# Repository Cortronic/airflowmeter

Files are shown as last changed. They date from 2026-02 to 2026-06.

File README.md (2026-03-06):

# Zero-Pressure Compensated Airflow Meter

<p align="left">
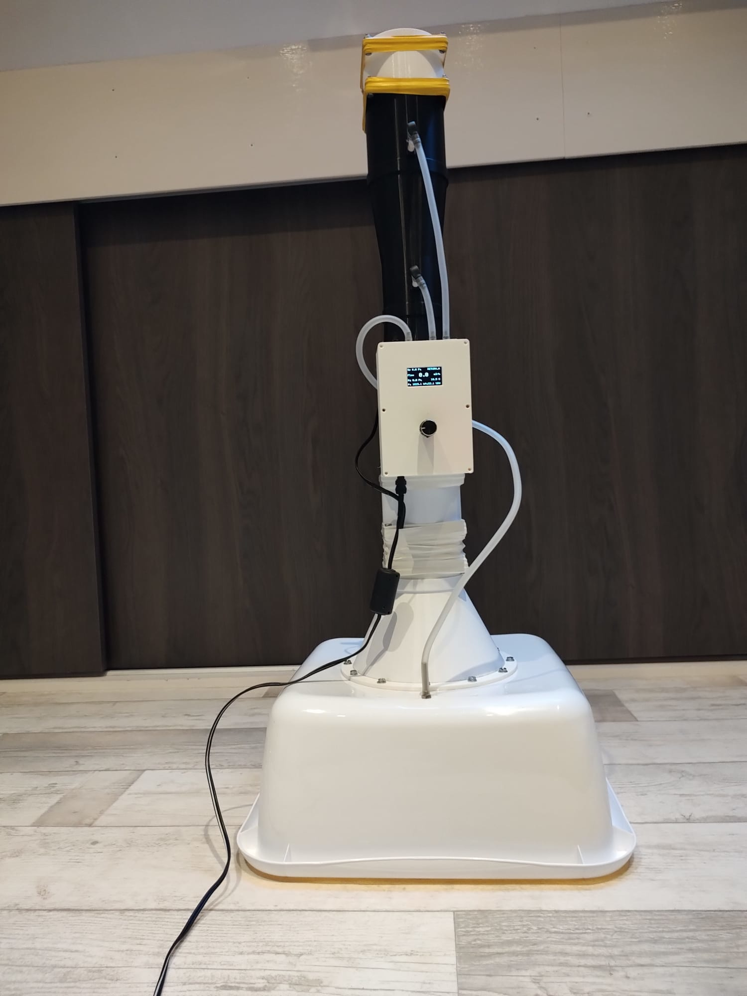
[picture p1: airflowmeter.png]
  
</p>

An open-source, high-precision instrument designed for measuring air flow in residential ventilation systems (HRV/MVHR). By using active zero-pressure compensation, this device eliminates its own pneumatic resistance, providing "invisible" measurements that do not disturb the ventilation system's balance.

## 1. Core Principle

Traditional flow hoods create backpressure, leading to underestimated flow readings. This device uses a secondary **SDP800-500PA** differential pressure sensor to monitor the pressure inside the hood. An integrated **Arctic S8038-10K fan** is controlled via a PID loop to maintain exactly $0.0\text{ Pa}$ relative to the room.

---

## 2. Hardware Architecture

The **ESP32-WROOM** utilizes two independent I2C buses to ensure high-speed data acquisition without bus collisions between identical sensors.

### Pinout Configuration

| Component | Function | ESP32 GPIO | Notes |
| --- | --- | --- | --- |
| **I2C Bus 0** | Data / Clock | **21 / 22** | BME280, OLED, SDP800 (Venturi) |
| **I2C Bus 1** | Data / Clock | **25 / 26** | SDP800 (Zero-Pressure Sensor) |
| **Encoder** | CLK / DT / SW | **2, 4, 15** | Menu & Calibration |
| **PWM Fan** | Speed Control | **27** | 25kHz PWM signal |

---

## 3. User Interface & Menu Structure

The 1.3" OLED (SH1106) provides a high-density data overview using a context-aware interface.

### Navigation Logic

* **Short Press:** Opens the **Quick-Profile Menu** to switch between calibrated profiles (Axial/Radial - Supply/Extract).
* **Long Press (>2s):** Enters the **System Menu** (Back, Tune Zero-Comp, Tune Flow, Tune PID).

### Display Layout (Measurement Mode)

The screen is optimized for the SH110X library using `textsize 1` and `textsize 2`.

| Position | Content | Example |
| --- | --- | --- |
| **Top Left** | Active Setpoint | `Set: 1.25 Pa` |
| **Top Right** | Profile Name | `RAD-SUPPLY` |
| **Center** | **Flow Rate** | **125.4 m3/h** |
| **Row 3** | Hood P / Temp | `P: 0.1 Pa` / `21.2 C` |
| **Bottom** | Baro / Hum | `1014 hPa` / `42 %` |

---

## 4. Interactive Calibration (Live-Trim)

The device uses a "Live-Trim" methodology. Settings are automatically saved to the active profile in the **NVS Flash** memory (`Preferences.h`).

* **Tune Zero-Comp:** Adjust the setpoint (range -25 to +25 Pa) while connected to the [test bench](https://github.com/Cortronic/testbench_airflowmeter) to compensate for air impingement (common in radial valves).
* **Tune Flow:** Rotate the encoder to align the meter's flow reading with the [reference Test Bench](https://github.com/Cortronic/testbench_airflowmeter).
* **Tune PID:** Select P, I, or D using **inverse video highlighting**. Adjust parameters in real-time and observe fan stability immediately.

---

## 5. Scientific Calculations

### Air Density ($\rho$)

Precision is maintained by calculating the density of moist air using the **Magnus-Tetens** approximation:

$$\rho = \frac{p_{dry}}{R_d \cdot T} + \frac{p_{vapor}}{R_v \cdot T}$$

### Volumetric Flow ($Q$)

Calculated based on the pressure differential across the Venturi throat:

$$Q = 3600 \cdot C_d \cdot A_{throat} \cdot \sqrt{\frac{2 \cdot \Delta P}{\rho \cdot (1 - \beta^4)}}$$

Where Beta ($$\beta$$) equals to:

$$\beta = \frac{D_{throat}}{D_{inlet}}$$

---

## 6. Manufacturing & Assembly

### 3D Printing

* **Material:** **PETG** (0.2mm layer height) for structural integrity and heat resistance.
* **Venturi Tube:** Printed in three sections (Inlet, Throat, Outlet) and bonded with **epoxy resin**.
* **Direct Drive:** Highly recommended to minimize stringing in PETG parts.

### Aerodynamics & Pressure Sensing

* **Dual Piezometric Rings:** The final Venturi design features integrated pressure rings at both the inlet and the throat. Each ring averages the static pressure from multiple points to ensure high accuracy.
* **Flow Hood Sensing:** The flow hood utilizes a 12-port averaging ring (2.5mm ports) to provide a stable signal for the zero-pressure logic.
* **Reversible Adapters:** Custom adapters allow the flow hood to be mounted on either side of the core assembly. This allows switching between supply and extract measurements while maintaining optimal aerodynamic orientation for the fan and Venturi.

---

## 7. License

This project is licensed under the **MIT License**.

---

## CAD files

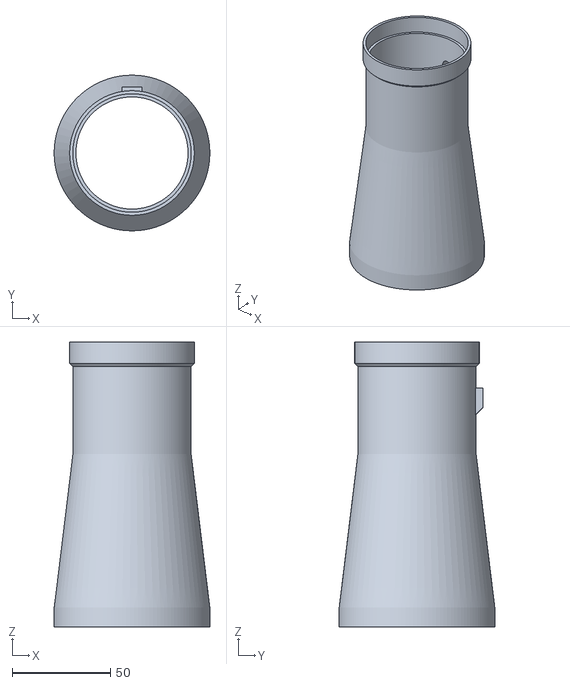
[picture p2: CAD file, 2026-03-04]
stl/venturi.stl
79.2 x 79.2 x 145.0

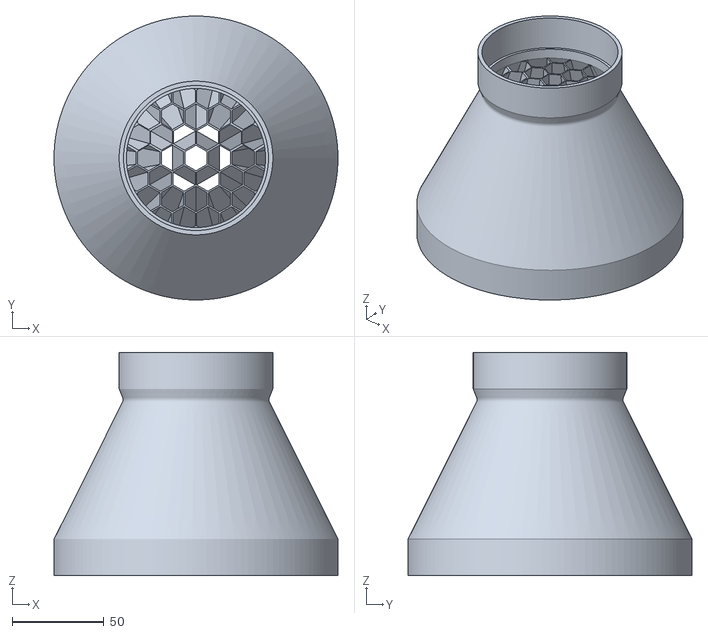
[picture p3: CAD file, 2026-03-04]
stl/adapter_v1.0.stl
155.2 x 155.2 x 122.0

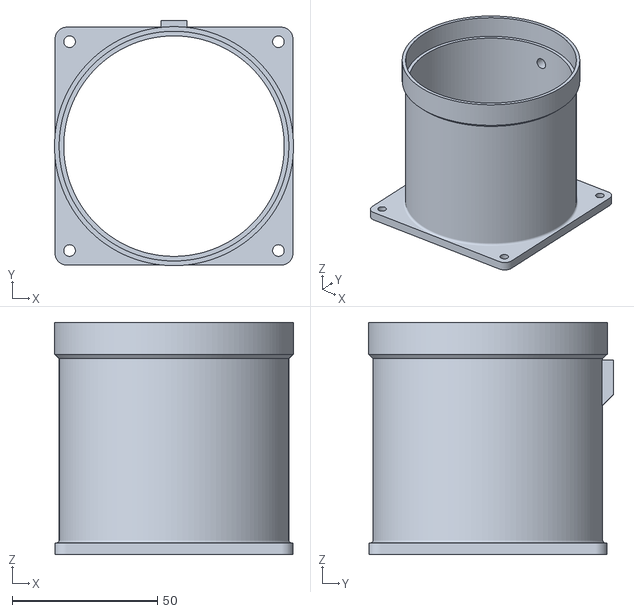
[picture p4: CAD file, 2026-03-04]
stl/Inlet.stl
82.4 x 84.5 x 80.0

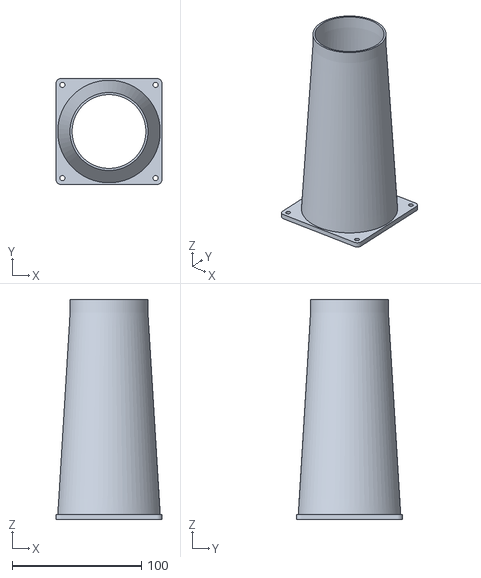
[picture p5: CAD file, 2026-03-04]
stl/outlet.stl
82.0 x 82.0 x 170.0

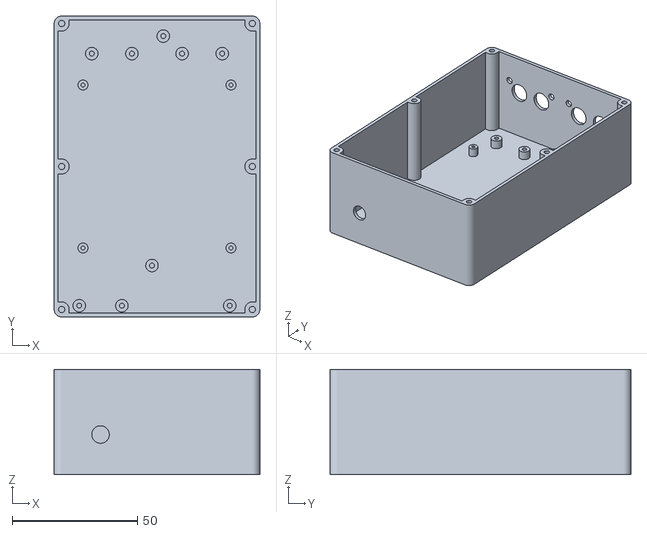
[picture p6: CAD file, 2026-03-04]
stl/bodycase.stl
82.0 x 120.0 x 42.0

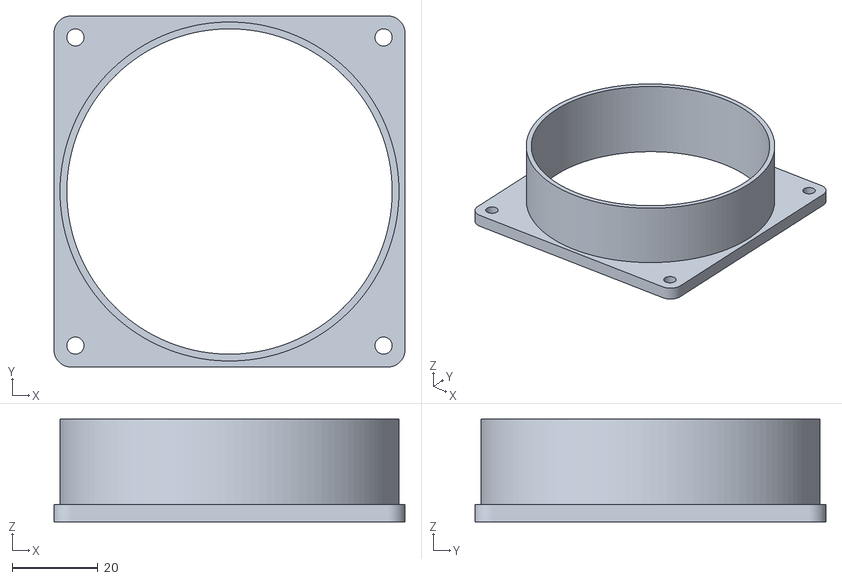
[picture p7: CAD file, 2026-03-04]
stl/adapterflange.stl
82.0 x 82.0 x 24.0

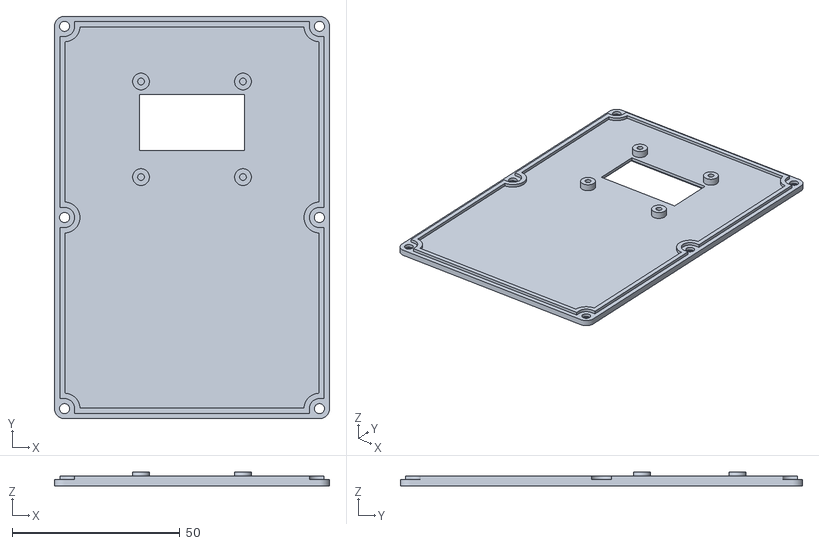
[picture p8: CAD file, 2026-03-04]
stl/bodylid.stl
82.0 x 120.0 x 4.30

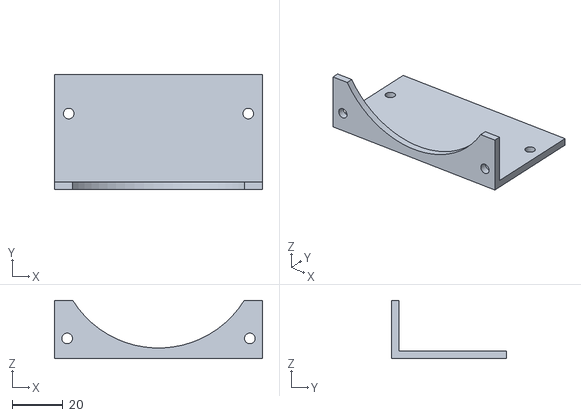
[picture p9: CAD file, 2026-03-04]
stl/steun-behuizing.stl
82.0 x 45.5 x 23.0

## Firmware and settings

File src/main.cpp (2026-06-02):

#include <Arduino.h>

#include <Preferences.h>
#include <Wire.h>
#include <AiEsp32RotaryEncoder.h>
#include <AiEsp32RotaryEncoderNumberSelector.h>
#include <SensirionCore.h>
#include <SensirionI2CSdp.h>
#include <Adafruit_SH110X.h>
#include <Adafruit_Sensor.h>
#include <Adafruit_BME280.h>
#include <PID_v1.h>
#include <Smoothed.h>
#include "fan.h"
#include "venturi.h"
#include "main.h"

// Pin definitions
// 12C pins
const int I2C_SDA0_PIN = 21;
const int I2C_SCL0_PIN = 22;
const int I2C_SDA1_PIN = 25;
const int I2C_SCL1_PIN = 26;

// Rotary encoder
const int ROTARY_ENCODER_A_PIN = 2; // 18;
const int ROTARY_ENCODER_B_PIN = 4; //19;
const int ROTARY_ENCODER_BUTTON_PIN = 15; //5;
const int ROTARY_ENCODER_STEPS = 4;

// Display
const int I2C_ADDRESS_DISPLAY = 0x3C;
const int I2C_ADDRESS_BME280  = 0x76;
const int I2C_ADDRESS_SDP810  = 0x25;

// PWM settings
const int PWM_FAN_PIN = 27;
const int PWM_FAN_CHAN = 0;
const int PWM_FREQ = 25000;    // 25 kHz frequency for computer fans
const int PWM_RESOLUTION = 10; // 10-bit resolution (0-1023)
const int PWM_DITHER_RESOLUTION = 2; // 2 bits of dithering for finer control

// paramaters for button press detection
const unsigned long shortPressAfterMiliseconds = 50;   // how long short press shoud be.
                                                       // Do not set too low to avoid bouncing (false press events).
const unsigned long longPressAfterMiliseconds = 1000;  // how long long press shoud be.

AiEsp32RotaryEncoder *rotaryEncoder = new AiEsp32RotaryEncoder(ROTARY_ENCODER_A_PIN, ROTARY_ENCODER_B_PIN,
  ROTARY_ENCODER_BUTTON_PIN, -1, ROTARY_ENCODER_STEPS, false);
AiEsp32RotaryEncoderNumberSelector numberSelector = AiEsp32RotaryEncoderNumberSelector();

Fan fan(PWM_FAN_PIN, PWM_FAN_CHAN, PWM_FREQ, PWM_RESOLUTION, PWM_DITHER_RESOLUTION);
// Venturi
Venturi venturi;

Preferences preferences;

Smoothed<float> zeroPressure;
Smoothed<float> flowPressure;
Smoothed<float> pressureAmbient;
Smoothed<float> temperatureAmbient;
Smoothed<float> humidityAmbient;
Smoothed<float> calibration;

/**
 * Two hardware I2C busses, one for the display, the BME280 and one SPD810 sensor.
 * The other for the second SDP810 sensor, to avoid address conflict between the two sensors.
 * The display and BME280 are on the same bus as they are not time critical and can handle the occasional delay 
 * and do not interfere with the timing of the SDP810 sensors.
 */
TwoWire I2C_A = TwoWire(0);
TwoWire I2C_B = TwoWire(1);

SensirionI2CSdp sdpFlow;
SensirionI2CSdp sdpZero;

// Initialize the OLED display using Wire library
Adafruit_SH1106G display(128, 64, &I2C_A);
Adafruit_BME280  bme280;     
hw_timer_t *timer0 = nullptr;
volatile bool ms10_passed = false;

ModeType modeType = MT_MEASURE;
ValveType valveType = VT_EXTRACT_RADIAL;
PidTuneType pidTuneType = PID_TUNE_NONE;

bool direction = false; // false for air extraction, true for air supply

// Define PID Variables
double pidSetpoint, pidInput, pidOutput;

// Specify the links and initial tuning parameters
double Kp = 6, Ki = 3, Kd = 0;
PID pid(&pidInput, &pidOutput, &pidSetpoint, Kp, Ki, Kd, REVERSE);

float offsetZeroPressure;
float offsetFlowPressure;

float compensationFactorEA = 0.0;
float compensationFactorER = 0.0;
float compensationFactorSA = 0.0;
float compensationFactorSR = 0.0;

float flowFactorExtractAxial = 0.985;
float flowFactorExtractRadial = 0.985;
float flowFactorSupplyAxial = 0.985;
float flowFactorSupplyRadial = 0.985;

static void  loadPreferences();
static void  setupRotaryEncoder();
static void  loopRotaryEncoder();
static void  readPressureSensors();
static float calculateZeroCompensationPressure();
static void  setupTimer0();
static void  initDisplay(void);
static void  displayAdjustSensorOffsetsProgress(int16_t progress);
static void  displayAdjustSensorOffsets(const char *sensor);
static void  displayTextNumber(const char *txt, float);
static void  displayMeasurements();
static void  displaySelectMode(ModeType type);
static void  displaySelectTunePID(PidTuneType type);
static void  displaySelectValveMode(ValveType type);
static void  displayCoefficientFlow(float coef);
static void  displayCoefficientZeroCompensation();
static void  initBME280();
static void  initSDP(SensirionI2CSdp&, TwoWire&);
static void  drawString(int16_t x, int16_t y, const String &text);
static float getDischargeCoefficient();
static void saveDischargeCoefficient(float coef);
//////////////////////////////////////////////////////////////////////////

// Interrupt Service Routine (ISR)
// IRAM_ATTR places the function in RAM for faster execution
void IRAM_ATTR Timer0_ISR() {
  ms10_passed = true;
  fan.handleDither(); // Handle fan dithering if enabled
}
//////////////////////////////////////////////////////////////////////////

void IRAM_ATTR readEncoder_ISR() {
    rotaryEncoder->readEncoder_ISR();
}
//////////////////////////////////////////////////////////////////////////

void IRAM_ATTR readButton_ISR() {
    rotaryEncoder->readButton_ISR();
}
//////////////////////////////////////////////////////////////////////////

void setup() {
  Serial.begin(115200);

  Serial.println("\nAirflowmeter is starting up...");

  loadPreferences();

  // setup RotaryEncoder
  setupRotaryEncoder();

  // Configure PWM
  Serial.println("Setup PWM for fan control");
  fan.begin();
  delay(500);

  // Start both busses
  I2C_A.begin(I2C_SDA0_PIN, I2C_SCL0_PIN, 700000);   // SDA, SCL
  I2C_B.begin(I2C_SDA1_PIN, I2C_SCL1_PIN, 100000);

  Serial.println("Setup Display");
  initDisplay();
  delay(500);
  Serial.println("Setup BME280");
  initBME280();
  delay(500);
  Serial.println("Setup SDP810 Flow");
  initSDP(sdpFlow, I2C_A);
  delay(500);
  Serial.println("Setup SDP810 Zero");
  initSDP(sdpZero, I2C_B);
  delay(500);

  Serial.println("setup smoothed average.");
  zeroPressure.begin(SMOOTHED_EXPONENTIAL, 2);
  flowPressure.begin(SMOOTHED_AVERAGE, 100);
  pressureAmbient.begin(SMOOTHED_AVERAGE, 40);
  humidityAmbient.begin(SMOOTHED_AVERAGE, 40);
  temperatureAmbient.begin(SMOOTHED_AVERAGE, 40);
  calibration.begin(SMOOTHED_AVERAGE, 200);

  bme280.takeForcedMeasurement();
  pressureAmbient.add(bme280.readPressure());
  temperatureAmbient.add(bme280.readTemperature());
  humidityAmbient.add(bme280.readHumidity());
  delay(500);

  pidSetpoint = 0.0;
  pidInput = 0.0;

  // turn the PID on
  Serial.println("turn the PID on.");
  pid.SetTunings(Kp, Ki, Kd);
  pid.SetMode(AUTOMATIC);
  // set output limits according to PWM resolution and dithering
  pid.SetOutputLimits(0, (((1 << PWM_RESOLUTION) - 1) << PWM_DITHER_RESOLUTION)); 
  pid.SetControllerDirection(direction ? REVERSE : DIRECT);
  
  delay(500);
  
  Serial.print("Setup timer interrupt\n");
  setupTimer0();
  delay(500);

  Serial.print("\n Setup done...\n\n");
  delay(500);
}
//////////////////////////////////////////////////////////////////////////

void loop() {
  static uint32_t loopcnt = 0;
  static uint32_t loopCount = 0;
  static uint32_t last_millis = 0;
  uint32_t ms = millis();
  
  ++loopCount;
  
  readPressureSensors();

  loopRotaryEncoder();

  // every 100ms
  if (ms >= last_millis + 100) {
    last_millis = ms;

    pidSetpoint = calculateZeroCompensationPressure(); 
    pidInput = zeroPressure.get();
    
    pid.Compute();
    // Apply PWM to fan
    fan.setSpeed(pidOutput);

    readPressureSensors();
    
    // every second
    if (loopcnt % 10 == 0) {

      // Only needed in forced mode! In normal mode, you can remove the next line.
      bme280.takeForcedMeasurement(); // has no effect in normal mode
      readPressureSensors();

      // get the measurements from the BME280
      pressureAmbient.add(bme280.readPressure()); // Pressure in Pa
      readPressureSensors();
      temperatureAmbient.add(bme280.readTemperature()); // Temperature in °C
      readPressureSensors();
      humidityAmbient.add(bme280.readHumidity()); // Humidity in %
      readPressureSensors();

      Serial.printf("delay: %u\n", millis() - ms);
      Serial.printf("Loop count: %u\n", loopCount); // 168 loops/second
      Serial.printf("Flow pressure: %.1f Pa\n", flowPressure.get());
      Serial.printf("Zero presssure: %.1f Pa\n", zeroPressure.get());
      Serial.printf("PWM fan dutycycle: %.1f%%\n", pidOutput/(((1 << PWM_RESOLUTION)-1) << PWM_DITHER_RESOLUTION) * 100);
      loopCount = 0;
      // 13ms
      // Serial.printf("Loop duaration: %u\n", millis()- last_millis);
    }
    
    // every 2 seconds
    if (loopcnt++ % 20 == 0) {
      if (modeType == MT_MEASURE 
          || modeType == MT_TUNE_ZERO_COMPENSATION
          || modeType == MT_CALIBRATE_FLOW
          || pidTuneType == PID_TUNE_P
          || pidTuneType == PID_TUNE_I
          || pidTuneType == PID_TUNE_D
        ) {
        displayMeasurements(); // takes 42ms
      }
    }

     // every minute
    if (loopcnt % 600 == 0) {
       venturi.setRho(pressureAmbient.get(), temperatureAmbient.get(), humidityAmbient.get());
       readPressureSensors();
    }
  }
}
//////////////////////////////////////////////////////////////////////////

static void setupTimer0() {
  // 1. Initialize timer
  //timerBegin(timer_number, divider, countUp)
  // Prescaler 80: 80MHz / 80 = 1MHz (1 microsecond per tick)
  timer0 = timerBegin(0, 80, true);

  // 2. Attach the ISR function
  timerAttachInterrupt(timer0, &Timer0_ISR, true);

  // 3. Set alarm to fire every 10000 ticks (10000 us = 10ms)
  // timerAlarmWrite(timer, microseconds, autoreload)
  timerAlarmWrite(timer0, 10000, true);

  // 4. Enable the alarm
  timerAlarmEnable(timer0);
}
//////////////////////////////////////////////////////////////////////////

static void setupRotaryEncoder() {
  rotaryEncoder->begin();
  rotaryEncoder->setup(&readEncoder_ISR, &readButton_ISR);
  numberSelector.attachEncoder(rotaryEncoder);

  // numberSelector.setRange parameters:
  float minValue = -20.0;      // set minimum value for example -12.0
  float maxValue = 20.0;       // set maxinum value for example 12.0
  float step = 0.1;            // set step increment, default 1, can be smaller steps like 0.5 or 10
  bool cycleValues = false;    // set true only if you want going to miminum value after maximum 
  unsigned int decimals = 1;   // set precision - how many decimal places you want, default is 0
  numberSelector.setRange(minValue, maxValue,  step, cycleValues, decimals);
  numberSelector.setValue(0.0); // sets initial value
}
//////////////////////////////////////////////////////////////////////////

static void setValveType(ValveType type) {
  valveType = type;

  venturi.setDischargeCoefficient(getDischargeCoefficient());
  
  switch(type) {
    case VT_EXTRACT_AXIAL:
    case VT_EXTRACT_RADIAL:
      direction = false;
      break;
    
    case VT_SUPPLY_AXIAL:  
    case VT_SUPPLY_RADIAL:
      direction = true;
      break;
  }
  pid.SetControllerDirection(direction ? REVERSE : DIRECT);

}
//////////////////////////////////////////////////////////////////////////

static float getFloat(const char* key, float value = NAN) {
  float f;
  preferences.begin("airflow", false);
  f = preferences.getFloat(key, value);
  preferences.end();
  return f == NAN ? 0.0 : f;
}
//////////////////////////////////////////////////////////////////////////

static void saveFloat(const char* key, float value) {
  preferences.begin("airflow", false);
  preferences.putFloat(key, value);
  preferences.end();
}
//////////////////////////////////////////////////////////////////////////

static void loadPreferences() {
  preferences.begin("airflow", true);

  offsetZeroPressure = preferences.getFloat(OFFSET_ZERO_PRESSURE, 0.0);
  offsetFlowPressure = preferences.getFloat(OFFSET_FLOW_PRESSURE, 0.0);

  float temp = preferences.getFloat(FLOW_COEF_EXTRACT_AXIAL, 0.0);
  if (temp >= FLOW_COEF_MIN && temp <= FLOW_COEF_MAX) {
    flowFactorExtractAxial = temp;
  }
  temp = preferences.getFloat(FLOW_COEF_EXTRACT_RADIAL, 0.0);
  if (temp >= FLOW_COEF_MIN && temp <= FLOW_COEF_MAX) {
    flowFactorExtractRadial = temp;
  }
  temp = preferences.getFloat(FLOW_COEF_SUPPLY_AXIAL, 0.0);
  if (temp >= FLOW_COEF_MIN && temp <= FLOW_COEF_MAX) {
    flowFactorSupplyAxial = temp;
  }
  temp = preferences.getFloat(FLOW_COEF_SUPPLY_RADIAL, 0.0);
  if (temp >= FLOW_COEF_MIN && temp <= FLOW_COEF_MAX) {
    flowFactorSupplyRadial = temp;
  }

  float inletDiameter = preferences.getFloat(KEY_VENTURI_INLET_DIAMETER, 0.076);
  float throatDiameter = preferences.getFloat(KEY_VENTURI_THROAT_DIAMETER, 0.057);
  venturi.begin(inletDiameter, throatDiameter, getDischargeCoefficient());
  venturi.setSmoothedFlowFactor(preferences.getFloat(KEY_VENTURI_SMOOTHING_FACTOR, 0.02));

  compensationFactorEA = preferences.getFloat(ZERO_COMPENSATION_FACTOR_EA, 0.0);
  compensationFactorER = preferences.getFloat(ZERO_COMPENSATION_FACTOR_ER, 0.0);
  compensationFactorSA = preferences.getFloat(ZERO_COMPENSATION_FACTOR_SA, 0.0);
  compensationFactorSR = preferences.getFloat(ZERO_COMPENSATION_FACTOR_SR, 0.0);

  // initialize the PID variables
  Kp = preferences.getFloat(Kp_KEY, Kp);
  Ki = preferences.getFloat(Ki_KEY, Ki);
  Kd = preferences.getFloat(Kd_KEY, Kd);

  preferences.end();
}
//////////////////////////////////////////////////////////////////////////

static void adjustSensorOffsetFlowPressure() {
  Serial.println("Adjusting offset flowsensor."); 
  for (size_t i = 0; i < 200; i++) {
    float differentialPressure;
    float temperature;
    uint16_t error = sdpFlow.readMeasurement(differentialPressure, temperature);
    if (error) {
       Serial.print("Error trying to execute readMeasurement() from flowsensor");
       break;
    }
    calibration.add(differentialPressure);
    if (i % 12 == 0) {
      displayAdjustSensorOffsetsProgress(i * 120 / 200);
    }
    delay(15);
  }

  offsetFlowPressure = calibration.get();
  saveFloat(OFFSET_FLOW_PRESSURE, offsetFlowPressure);
  Serial.printf("offset flow %f\n", offsetFlowPressure);
  delay(500); 
}
//////////////////////////////////////////////////////////////////////////

static void adjustSensorOffsetZeroPressure() {
  Serial.println("Adjusting offset zeropressuresensor."); 
  for (size_t i = 0; i < 200; i++) {
    float differentialPressure;
    float temperature;
    uint16_t error = sdpZero.readMeasurement(differentialPressure, temperature);
    if (error) {
       Serial.print("Error trying to execute readMeasurement() from zeropressuresensor");
       break;
    }
    calibration.add(differentialPressure);
    if (i % 12 == 0) {
      displayAdjustSensorOffsetsProgress(i * 120 / 200);
    }
    delay(15);
  }
  
  offsetZeroPressure = calibration.get();
  saveFloat(OFFSET_ZERO_PRESSURE, offsetZeroPressure);
  Serial.printf("offset zero %f\n", offsetZeroPressure);
  delay(500); 
}
//////////////////////////////////////////////////////////////////////////

static void adjustSensorOffsets() {
  displayAdjustSensorOffsets("Zero");
  adjustSensorOffsetZeroPressure();
  displayAdjustSensorOffsets("Flow");
  adjustSensorOffsetFlowPressure();
}
//////////////////////////////////////////////////////////////////////////

static float getZeroCompensationFactor() {
  switch (valveType) {
    case VT_EXTRACT_AXIAL:
      return compensationFactorEA;
    case VT_EXTRACT_RADIAL:
      return compensationFactorER;
    case VT_SUPPLY_AXIAL:
      return compensationFactorSA;
    case VT_SUPPLY_RADIAL:
      return compensationFactorSR; 
  }
  return 0.0;
}
//////////////////////////////////////////////////////////////////////////

static void setZeroCompensationFactor(float factor) {
  switch (valveType) {
    case VT_EXTRACT_AXIAL:
      compensationFactorEA = factor;
      break;
    case VT_EXTRACT_RADIAL:
      compensationFactorER = factor;
      break;
    case VT_SUPPLY_AXIAL:
      compensationFactorSA = factor;
      break;
    case VT_SUPPLY_RADIAL:
      compensationFactorSR = factor; 
      break;
  }
}
//////////////////////////////////////////////////////////////////////////

static void saveZeroCompensationFactor(float factor) {
  
  switch (valveType) {
    case VT_EXTRACT_AXIAL:
      compensationFactorEA = factor;
      saveFloat(ZERO_COMPENSATION_FACTOR_EA, factor);
      break;
    case VT_EXTRACT_RADIAL:
      compensationFactorER = factor;
      saveFloat(ZERO_COMPENSATION_FACTOR_ER, factor);
      break;
    case VT_SUPPLY_AXIAL:
      compensationFactorSA = factor;
      saveFloat(ZERO_COMPENSATION_FACTOR_SA, factor);
      break;
    case VT_SUPPLY_RADIAL:
      compensationFactorSR = factor; 
      saveFloat(ZERO_COMPENSATION_FACTOR_SR, factor);
      break;
  }
}
//////////////////////////////////////////////////////////////////////////

static void restoreZeroCompensationFactors() {
  switch(valveType) {
    case VT_EXTRACT_AXIAL:
      compensationFactorEA = getFloat(ZERO_COMPENSATION_FACTOR_EA, 0.0);
      pidSetpoint = compensationFactorEA * flowPressure.get();
      break;
    case VT_EXTRACT_RADIAL:
      compensationFactorER = getFloat(ZERO_COMPENSATION_FACTOR_ER, 0.0);
      pidSetpoint = compensationFactorER * flowPressure.get();
      break;
    case VT_SUPPLY_AXIAL:
      compensationFactorSA = getFloat(ZERO_COMPENSATION_FACTOR_SA, 0.0);
      pidSetpoint = compensationFactorSA * flowPressure.get();
      break;
    case VT_SUPPLY_RADIAL:
      compensationFactorSR = getFloat(ZERO_COMPENSATION_FACTOR_SR, 0.0); 
      pidSetpoint = compensationFactorSR * flowPressure.get();
      break;
  }
}
////////////////////////////////////////////////////////////////////////// 

static float calculateZeroCompensationPressure() {
  return getZeroCompensationFactor() * flowPressure.get();
}
//////////////////////////////////////////////////////////////////////////

static void initNextMode(ModeType type) {

  modeType = type;

  switch (type) {
    
    case MT_SELECT:
      numberSelector.setRange(1, 6,  1, true, 0);
      numberSelector.setValue(MT_MEASURE);
      displaySelectMode(MT_MEASURE);
      break;

    case MT_MEASURE:
      displayMeasurements();
      break; 

    case MT_SELECT_VALVE:
      numberSelector.setRange(0, 3,  1, true, 0);
      numberSelector.setValue(valveType);
      displaySelectValveMode(valveType);
      break;

    case MT_TUNE_ZERO_COMPENSATION:
      numberSelector.setRange(ZERO_COMP_MIN, ZERO_COMP_MAX, ZERO_COMP_STEP, false, 3);
      numberSelector.setValue(getZeroCompensationFactor());
      displayMeasurements();
      break;

    case MT_CALIBRATE_FLOW:
      numberSelector.setRange(FLOW_COEF_MIN, FLOW_COEF_MAX, FLOW_COEF_STEP, false, 3);
      switch (valveType) {
        case VT_EXTRACT_AXIAL:
          numberSelector.setValue(getFloat(FLOW_COEF_EXTRACT_AXIAL, FLOW_COEF_DEFAULT));
          break;
        case VT_EXTRACT_RADIAL:
          numberSelector.setValue(getFloat(FLOW_COEF_EXTRACT_RADIAL, FLOW_COEF_DEFAULT));
          break;
        case VT_SUPPLY_AXIAL:
          numberSelector.setValue(getFloat(FLOW_COEF_SUPPLY_AXIAL, FLOW_COEF_DEFAULT));
          break;
        case VT_SUPPLY_RADIAL:
          numberSelector.setValue(getFloat(FLOW_COEF_SUPPLY_RADIAL, FLOW_COEF_DEFAULT));
          break;
      }
      displayCoefficientFlow(numberSelector.getValue());
      break;

    case MT_TUNE_PID:
      pidTuneType = PID_TUNE_NONE;
      numberSelector.setRange(0, 3, 1, true, 0);
      numberSelector.setValue(PID_TUNE_NONE);
      displaySelectTunePID(PID_TUNE_NONE);
      break;

    case MT_ADJUST_OFFSET:
      adjustSensorOffsets();
      modeType = MT_MEASURE;
      displayMeasurements();
      break;
  }
}
//////////////////////////////////////////////////////////////////////////

static void on_button_short_click() {
 
  switch (modeType) {
    
    case MT_SELECT:
      initNextMode((ModeType)(uint8_t)numberSelector.getValue()); 
      break;

    case MT_MEASURE:
      initNextMode(MT_SELECT_VALVE);
      break;

    case MT_SELECT_VALVE:
      setValveType((ValveType)(uint8_t)numberSelector.getValue());
      initNextMode(MT_MEASURE);
      break;

    case MT_TUNE_ZERO_COMPENSATION:
      saveZeroCompensationFactor(numberSelector.getValue());
      initNextMode(MT_MEASURE);
      break;

    case MT_CALIBRATE_FLOW:
      saveDischargeCoefficient(numberSelector.getValue());
      initNextMode(MT_MEASURE);
      break;

    case MT_TUNE_PID:
      switch (pidTuneType) {
        case PID_TUNE_NONE:
          switch((PidTuneType)(uint8_t)numberSelector.getValue()) {
            case PID_TUNE_NONE:
              initNextMode(MT_SELECT);
              break;
            case PID_TUNE_P:
              pidTuneType = PID_TUNE_P;
              numberSelector.setRange(0, 20, 0.1, false, 1);
              numberSelector.setValue(Kp);
              displayMeasurements();
              break;
            case PID_TUNE_I:
              pidTuneType = PID_TUNE_I;
              numberSelector.setRange(0, 10, 0.1, false, 1);
              numberSelector.setValue(Ki);
              displayMeasurements();
              break;
            case PID_TUNE_D:
              pidTuneType = PID_TUNE_D;
              numberSelector.setRange(0, 10, 0.1, false, 1);
              numberSelector.setValue(Kd);
              displayMeasurements();
              break;
          }
          break;

        case PID_TUNE_P:
          saveFloat(Kp_KEY, numberSelector.getValue());
          initNextMode(MT_TUNE_PID);
          break;

        case PID_TUNE_I:
          saveFloat(Ki_KEY, numberSelector.getValue());
          initNextMode(MT_TUNE_PID);
          break;
          
        case PID_TUNE_D:
          saveFloat(Kd_KEY, numberSelector.getValue());
          initNextMode(MT_TUNE_PID);
          break; 
      }
      break;           
  }
}
//////////////////////////////////////////////////////////////////////////
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

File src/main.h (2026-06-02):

#pragma once

typedef enum {
  MT_SELECT = 0,
  MT_MEASURE = 1,
  MT_SELECT_VALVE = 2,
  MT_TUNE_ZERO_COMPENSATION = 3,
  MT_CALIBRATE_FLOW = 4,
  MT_TUNE_PID = 5,
  MT_ADJUST_OFFSET = 6,
} ModeType;
extern ModeType modeType;

typedef enum {
  VT_EXTRACT_AXIAL = 0,
  VT_EXTRACT_RADIAL = 1,
  VT_SUPPLY_AXIAL = 2,
  VT_SUPPLY_RADIAL = 3,
} ValveType;
extern ValveType valveType;

typedef enum {
  PID_TUNE_NONE = 0,
  PID_TUNE_P = 1,
  PID_TUNE_I = 2,
  PID_TUNE_D = 3,
} PidTuneType;
extern PidTuneType pidTuneType;

#define ZERO_COMP_MIN -0.5
#define ZERO_COMP_MAX 0.5
#define ZERO_COMP_STEP 0.001
#define ZERO_COMP_DEFAULT 0.0

#define FLOW_COEF_MIN 0.7
#define FLOW_COEF_MAX 1.0
#define FLOW_COEF_STEP 0.001
#define FLOW_COEF_DEFAULT 0.965

// preferences keys
#define KEY_VENTURI_INLET_DIAMETER "inletDia"
#define KEY_VENTURI_THROAT_DIAMETER "throadDia"
#define KEY_VENTURI_SMOOTHING_FACTOR "smoothFactor"
#define OFFSET_ZERO_PRESSURE "offsetZero"
#define OFFSET_FLOW_PRESSURE "offsetFlow"
#define FLOW_COEF_EXTRACT_AXIAL "coefExtractAx"
#define FLOW_COEF_EXTRACT_RADIAL "coefExtractRd"
#define FLOW_COEF_SUPPLY_AXIAL "coefSupplyAx"
#define FLOW_COEF_SUPPLY_RADIAL "coefSupplyRd"
#define ZERO_COMPENSATION_FACTOR_EA "compFactEA"
#define ZERO_COMPENSATION_FACTOR_ER "compFactER"
#define ZERO_COMPENSATION_FACTOR_SA "compFactSA"
#define ZERO_COMPENSATION_FACTOR_SR "compFactSR"
#define Kp_KEY "Kp"
#define Ki_KEY "Ki"
#define Kd_KEY "Kd"

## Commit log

2026-02-23 Refactor PID controller implementation and enhance display functionality for tuning parameters
2026-02-23 Enhance measurement display by adding PID tuning modes to the loop condition
2026-02-23 Update .gitignore and README.md for clarity and accuracy
    - Modified .gitignore to remove trailing slash from .airflowmeter and keep data directory as a single entry.
    - Changed project title in README.md from "Venturi Flow Meter" to "3D-printed Venturi Flow Meter" for better description.
2026-02-23 Remove unused calibration functions and clean up main.cpp; ensure newline at end of main.h
2026-02-23 Reorganize rotary encoder pin definitions in main.cpp for clarity
2026-02-23 Enhance README.md with detailed project architecture, hardware configuration, and calibration instructions
2026-02-23 Fix LaTeX formatting for density and flow rate equations in README.md
2026-02-23 Add explanation for Beta in Venturi flow equation in README.md
2026-02-23 Enhance LaTeX formatting for density and flow rate equations in README.md
2026-02-23 Fix display formatting for pressure and measurement mode in main.cpp
    [main.cpp]
2026-03-04 Refactor zero compensation calibration range and update display messages
2026-03-04 Refactor mode type enumeration and reorganize PID tuning definitions
2026-03-04 Update PID tuning display logic and initialize PID tune type
2026-03-04 Refactor code structure for improved readability and maintainability
    [Inlet.stl, adapter_v1.0.stl, adapterflange.stl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]
2026-03-04 Implement feature X to enhance user experience and optimize performance
    [venturi.stl]
2026-03-06 Add links to test bench in calibration instructions
    Updated links in the calibration section to point to the test bench repository.
2026-03-07 Remove unused calibration pin definitions and related PWM settings for cleaner code
2026-03-07 Refactor hood valve types to valve types for improved clarity and consistency
2026-03-08 Rename zero calibration mode to tune zero compensation for improved clarity
2026-03-08 Refactor flow factor variables and related functions for improved clarity and consistency
2026-03-08 Refactor flow factor variables for axial and radial configurations to improve clarity and consistency
2026-03-09 Add sensor offset adjustment functionality and related display updates
2026-03-31 Fix formatting in loopRotaryEncoder function for improved readability
    [main.cpp]
2026-03-31 Add preference keys for sensor offsets and flow coefficients for improved clarity and consistency
2026-03-31 Refactor displayCoefficientFlow function to accept a coefficient parameter and update PID variable initialization in loadPreferences function for improved clarity and functionality
2026-04-14 Implement fan control class with PWM configuration and dithering support; refactor venturi constants and flow coefficient handling for improved clarity and functionality
2026-04-14 Refactor fan class method declarations for consistency and update mode enumeration values for improved clarity in main logic
2026-06-02 Refactor fan control and integrate Venturi flow measurement
    - Updated Fan class to include methods for setting speed as a percentage and retrieving speed in both raw and percentage formats.
    - Integrated Venturi class for flow measurement, including methods for updating flow based on pressure differentials and environmental conditions.
    - Removed redundant Venturi constants and streamlined flow coefficient handling.
    - Implemented adaptive and double exponential moving average filters for smoother control outputs in PID controllers.
    - Enhanced PID controller with new tuning parameters and improved error handling.
    - Added TEMA filter for output smoothing to reduce noise and prevent aggressive ch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
    [main.cpp, main.h]
